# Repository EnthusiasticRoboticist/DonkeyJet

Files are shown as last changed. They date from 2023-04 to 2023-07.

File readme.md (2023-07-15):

# Workspace for DonkeyJet [Under ACTIVE CONSTRUCTION]

Introducing my ongoing robotics project, currently named **DonkeyJet**, inspired by the [Donkey Car project](https://www.donkeycar.com/). This mobile robot is built on an RC car frame and powered by Jetson Nano, providing a hands-on platform for practicing robotics knowledge. The goal is to continually enhance its capabilities while exploring various aspects of robotics technology. While I am not certain about the name DonkeyJet, I invite you to follow me on this exciting journey of discovery as I document my progress and share insights with fellow enthusiasts in my weblog [here](https://www.enthusiasticroboticist.com/).

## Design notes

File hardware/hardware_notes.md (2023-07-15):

# Mechanical Info

### Car

https://www.nitrorcx.com/51c858-16-deaertsct-aagreen-24g.html

## Gear Tooth Sensor IC

- [Sensor WebPage and CAD files](https://www.allegromicro.com/en/products/sense/magnetic-speed/general-purpose-speed-sensor-ics/ats668lsm)
- [Datasheet](https://www.allegromicro.com/~/media/Files/Datasheets/ATS668-Datasheet.ashx)
- [Purchase Link](https://www.digikey.com/short/pbw4z55j)

### Number of teeth of gears

- Motor Gear: 16
- Main shaft Gear: 50
- Differential Gear Box:
  - Drive Pinion Gear: 20 or 11 (not important actually)
  - Ring Gear: 39 (important)

- Wheel Diameter: 72.91 mm

## Clipboard

PC7 (ICP3/CLK0/OC4A)
X: 8.92
Y: -10.67

# Screws:
- M2x6    (8)
- M3x10   (3)

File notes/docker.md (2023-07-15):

# Docker Images

We are using docker for this project. [Read more here](https://www.enthusiasticroboticist.com/blog/ros-2-on-jetson-nano-using-docker/).

- [setup remote docker build](https://youtu.be/YX2BSioWyhI)
- add Jetson IP to `/etc/hosts` as `jetson`
- some docker docs
  - https://docs.docker.com/build/building/multi-platform/
- https://www.docker.com/blog/multi-arch-build-and-images-the-simple-way/

Setup for building docker image for multiple platforms which images are built natively on the corresponding hardware without emulation.

```bash
/usr/bin/dockerd -H fd:// --containerd=/run/containerd/containerd.sock
export REGISTRY="<the docker registry to be used, or dockerhub user>"

docker context create jetson --docker "host=tcp://jetson:2375"
docker context create localamd64 --docker "host=unix:///var/run/docker.sock"

# just one time
# docker buildx create --use  --driver-opt network=host --config=buildkitd.toml --name MultiPlatform
docker buildx create --use --driver-opt network=host --config=buildkitd-arm64.toml --name mybuilder jetson
docker buildx create --append --driver-opt network=host --config=buildkitd-amd64.toml --name mybuilder localamd64
```

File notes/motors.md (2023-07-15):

# motors

[Read more here](https://www.enthusiasticroboticist.com/blog/actuation-and-pca9685-with-ros-2-on-jetson-nano/)

```bash
docker run \
  --name realsense \
  --rm \
  -it \
  --privileged \
  --network host \
  -e DISPLAY \
  --runtime nvidia \
  --gpus all \
  ${REGISTRY}/ros2_realsense:latest \
  bash

  -v /dev/input:/dev/input \
  -v /dev/v4l:/dev/v4l \
  -v /dev:/dev \
  -v /proc:/proc \
  -v /sys:/sys \
# issue about Jetson.GPIO inside docker: 
# https://forums.developer.nvidia.com/t/jetson-gpio-not-working-on-python-inside-the-container/180435
python -m pip install adafruit-circuitpython-servokit Jetson.GPIO
i2cdetect -y -r 1
```

- [More about I2C in Linux](https://www.youtube.com/watch?v=-1PHQYRbAm8&ab_channel=Johannes4GNU_Linux)
- [PCA9685 datasheet](https://cdn-shop.adafruit.com/datasheets/PCA9685.pdf)
- [PCA9685 Adafruit info](https://cdn-learn.adafruit.com/downloads/pdf/16-channel-pwm-servo-driver.pdf)
- The I2C address is `0x40`.
- [About Actutation](http://docs.donkeycar.com/parts/actuators/)
- [I2C in Linux](http://embeddedcraft.org/eclinux/linuxi2c.html)

## PWM Signals
- PWM Period: 20 ms, PWM Frequency: 50Hz
- 1ms - 2ms high or Duty cycle: 1% - 10% with 50Hz freq
- Servo from left to right
- Throttle form full backward to full forward.

```
freq = 60
prescaler = 0x66 = 25M / (4096 * frequency)
i2cset -y 1 0x40 0x00 0x90
i2cset -y 1 0x40 0xFE 0x66
i2cset -y 1 0x40 0x00 0xA0

# steering
i2cset -y 1 0x40 0x0A 0x00 && \
  i2cset -y 1 0x40 0x0B 0x00 && \
  i2cset -y 1 0x40 0x0C 0xFA && \
  i2cset -y 1 0x40 0x0D 0x00

i2cset -y 1 0x40 0x0A 0x00 0x00 0x4F 0x01 i

# throttle (85 instead of 6f is good value for test)
i2cset -y 1 0x40 0x06 0x00 && \
i2cset -y 1 0x40 0x07 0x00 && \
i2cset -y 1 0x40 0x08 0x85 && \
i2cset -y 1 0x40 0x09 0x01

i2cset -y 1 0x40 0x06 0x00 0x00 0x4F 0x01 i

```

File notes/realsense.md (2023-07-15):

# Docker image with CUDA, ROS2, Realsense
- https://dev.intelrealsense.com/docs/nvidia-jetson-tx2-installation

```bash
docker buildx build \
  --platform linux/amd64,linux/arm64 \
  -f realsense.Dockerfile \
  --build-arg BASE_IMAGE=${REGISTRY}/ros2_base2:latest \
  -t ${REGISTRY}/ros2_realsense:latest \
  --push .

# on jetson run only once
sudo curl https://raw.githubusercontent.com/IntelRealSense/librealsense/master/config/99-realsense-libusb.rules -o /etc/udev/rules.d/99-realsense-libusb.rules \
  && sudo udevadm control --reload-rules \
  && sudo udevadm trigger

docker run \
  --name ros2_realsense \
  --rm \
  -it \
  --runtime nvidia \
  --network host \
  --gpus all \
  --privileged \
  -v /dev/bus/usb/:/dev/bus/usb/ \
  -e DISPLAY \
  ${REGISTRY}/ros2_realsense:latest \
  bash

# to test run the following in the docker container
rs-depth

ros2 launch realsense2_camera rs_launch.py initial_reset:=true
```

# Prepare IMU data from D435i for ROS 2

```bash
MOUNT_WS
cd ws/donkeyJet

rs-enumerate-devices  # check the device
# once
sudo udevadm control --reload-rules
udevadm trigger

docker pull ${REGISTRY}/ros2_realsense:latest

#run this to load software to T265
docker run \
  --name ros2_base \
  --rm \
  --privileged \
  -v /dev/bus/usb/:/dev/bus/usb/ \
  ${REGISTRY}/ros2_realsense_latest:latest \
  rs-pose

# for development on host:
docker run \
  --name ros2_base \
  --rm \
  -it \
  --runtime nvidia \
  --network host \
  --gpus all \
  --privileged \
  -e DISPLAY \
  -v /dev/bus/usb/:/dev/bus/usb/ \
  -v `pwd`/ros2_ws/src:/root/ros2_ws/src \
  -v `pwd`/ros2_ws_tutorial/src:/root/ros2_ws_tutorial/src \
  ${REGISTRY}/ros2_realsense:latest \
  bash 

# ${REGISTRY}/ros2_realsense:latest \

colcon build --symlink-install

# for test on jetson:
export JETSON_IP=
export HOST=""
export HOST="-H $JETSON_IP"
function RUN(){
  docker $HOST run --name ros2_ws --rm -it \
    --runtime nvidia --network host \
    --gpus all -e DISPLAY \
    --privileged -v /proc:/proc -v /dev:/dev -v /sys:/sys \
    ${REGISTRY}/ros2_ws:latest bash -ic "$@"
}

function BUILD_AND_RUN(){
  docker $HOST pull ${REGISTRY}/ros2_realsense:latest && \
  docker $HOST buildx build -f ros2_ws.Dockerfile  --build-arg BASE_IMAGE=${REGISTRY}/ros2_realsense:latest   -t ${REGISTRY}/ros2_ws:latest . && \
  RUN "$@"
}

ros2 run bot_hardware realsense
BUILD_AND_RUN "ros2 run bot_hardware realsense --ros-args --log-level debug" # --ros-args --log-level debug

ros2 run tf2_tools view_frames.py
ros2 launch realsense2_camera rs_launch.py
ros2 run tf2_ros tf2_echo camera_pose_frame odom_frame

reset; colcon build && \
  ./build/bot_hardware/bot_hardware_test --gtest_filter="realsense_lib.*"
```

# build realsense image
```bash
docker buildx build \
  --platform linux/amd64,linux/arm64 \
  -f realsense.Dockerfile \
  --build-arg BASE_IMAGE=${REGISTRY}/ros2_base:latest \
  -t ${REGISTRY}/ros2_realsense:latest \
  --push .
```

## Expected IMU type

- More information about message type can be found [here](https:docs.ros2.org/foxy/api/nav_msgs/msg/Odometry.html).
- Example of including librealsense SKD into a [ros2 CMakeLists.txt file](https:github.com/IntelRealSense/realsense-ros/blob/ros2-development/realsense2_camera/CMakeLists.txt)
- Realsense How-to [wiki page](https:github.com/IntelRealSense/librealsense/wiki/API-How-To).
- Realsense cpp [IMU example](https:github.com/GruffyPuffy/imutest/blob/master/imutest.cpp).

# Notes

- You need to plug the USB first, then run the container. When you re-plug the USB, you need to kill the docker container and re-run it. Otherwise, realsense device would not be visible within the container.
- Sometimes the IMU streams are not coming. I don't know why. Re-plugging could help.
- reading imu info
- T265 doesn't have memory for firmware and usb volume bind and container issues

```cpp
rs2::pipeline pipe;
rs2::config cfg;
cfg.enable_stream(RS2_STREAM_ACCEL);
cfg.enable_stream(RS2_STREAM_GYRO);
cfg.enable_stream(RS2_STREAM_DEPTH);
pipe.start(cfg);

while (true)
{
  rs2::frameset frameset = pipe.wait_for_frames(1000);

  if (rs2::motion_frame accel_frame = frameset.first_or_default(RS2_STREAM_ACCEL))
  {
    rs2_vector accel_sample = accel_frame.get_motion_data();
    std::cout << "Accel:" << accel_sample.x << ", " << accel_sample.y << ", " << accel_sample.z << std::endl;
  }

  if (rs2::motion_frame gyro_frame = frameset.first_or_default(RS2_STREAM_GYRO))
  {
    rs2_vector gyro_sample = gyro_frame.get_motion_data();
    std::cout << "Gyro:" << gyro_sample.x << ", " << gyro_sample.y << ", " << gyro_sample.z << std::endl;
  }
}

auto callback = [&](const rs2::frame &frame)
{
  if (frame.is<rs2::frameset>())
  {
    std::cout << "Depth data" << std::endl;
  } else if (frame.is<rs2::motion_frame>())
  {
    auto motion = frame.as<rs2::motion_frame>();
    const auto &stream_type = motion.get_profile().stream_type();
    std::cout << "gyro: " << (stream_type == RS2_STREAM_GYRO)
              << ", accel: " << (stream_type == RS2_STREAM_ACCEL) << std::endl;
  } else if(frame.is<rs2::pose_frame>())
  {
    std::cout << "pose frame" << std::endl;
  }
};
```

```cpp
#include <librealsense2/rs.hpp>
#include <iostream>

int main()
{
  rs2::pipeline pipe;
  rs2::config cfg;
  cfg.enable_stream(RS2_STREAM_ACCEL);
  cfg.enable_stream(RS2_STREAM_GYRO);
  pipe.start(cfg);

  while (true) // Application still alive?
  {
    rs2::frameset frameset = pipe.wait_for_frames(1000);

    if (rs2::motion_frame accel_frame = frameset.first_or_default(RS2_STREAM_ACCEL))
    {
      rs2_vector accel_sample = accel_frame.get_motion_data();
      std::cout << "Accel:" << accel_sample.x << ", " << accel_sample.y << ", " << accel_sample.z << std::endl;
    }

    if (rs2::motion_frame gyro_frame = frameset.first_or_default(RS2_STREAM_GYRO))
    {
      rs2_vector gyro_sample = gyro_frame.get_motion_data();
      std::cout << "Gyro:" << gyro_sample.x << ", " << gyro_sample.y << ", " << gyro_sample.z << std::endl;
    }
  }
  return 0;
}
```

```cpp
#include <librealsense2/rs.hpp>
#include <iostream>

int main(){
  auto callback = [&](const rs2::frame &frame)
  {
    if (frame.is<rs2::frameset>())
    {
      std::cout << "Depth data" << std::endl;
    } else if (frame.is<rs2::motion_frame>())
    {
      auto motion = frame.as<rs2::motion_frame>();
      const auto &stream_type = motion.get_profile().stream_type();
      std::cout << "gyro: " << (stream_type == RS2_STREAM_GYRO)
                << ", accel: " << (stream_type == RS2_STREAM_ACCEL) << std::endl;
    } else if(frame.is<rs2::pose_frame>())
    {
      std::cout << "pose frame" << std::endl;
    }
  };

  rs2::pipeline pipe;
  rs2::config cfg;
  cfg.enable_stream(RS2_STREAM_ACCEL);
  cfg.enable_stream(RS2_STREAM_GYRO);
  cfg.enable_stream(RS2_STREAM_DEPTH); 

  std::this_thread::sleep_for(std::chrono::milliseconds(500));
  pipe.start(cfg, callback);
  while (true){}
  return 0;
}
```

```cpp
{
  auto callback = [&](const rs2::frame &frame)
  {
    // callback code as before
  };
  rs2::context ctx;
  rs2::pipeline pipe_t265;
  rs2::config rs_cfg_t265;
  rs2::pipeline pipe_d435;
  rs2::config rs_cfg_d435;

  for (auto dev : ctx.query_devices())
  {
    std::cout << dev.get_info(RS2_CAMERA_INFO_NAME) << std::endl;
    if (strcmp(dev.get_info(RS2_CAMERA_INFO_NAME), "Intel RealSense D435") == 0)
    {
      rs_cfg_d435.enable_stream(RS2_STREAM_DEPTH); // , 256, 144, RS2_FORMAT_Z16, 90
    }
    else if (strcmp(dev.get_info(RS2_CAMERA_INFO_NAME), "Intel RealSense T265") == 0)
    {
      rs_cfg_t265.enable_stream(RS2_STREAM_ACCEL);
      rs_cfg_t265.enable_stream(RS2_STREAM_GYRO);
      rs_cfg_t265.enable_stream(RS2_STREAM_POSE);
    }
  }

  pipe_d435.start(rs_cfg_d435, callback);
  pipe_t265.start(rs_cfg_t265, callback);

  while (true)
  {
  }
}
```

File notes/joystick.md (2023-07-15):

# Joystick (Controller)

[Read more](https://www.enthusiasticroboticist.com/blog/using-bluetooth-controller-with-ros-2-on-jetson-nano/)
[About Joystick in Linux](https://opencoursehub.cs.sfu.ca/bfraser/grav-cms/cmpt433/links/files/2022-student-howtos/LinuxJoystick.hLibrary.pdf).

### Test the joystick

With GUI
```bash
sudo apt install -y jstest-gtk
jstest-gtk
```

Without GUI
```bash
jstest /dev/input/js0
```

With ros
```
docker -H 192.168.68.68 pull ${REGISTRY}/ros2_base2:latest
docker -H 192.168.68.68 run \
  --rm -it  --runtime nvidia --network host \
  --gpus all --privileged \
  -v /dev:/dev -v /proc:/proc -v /sys:/sys \
  ${REGISTRY}/ros2_base2:latest \
  bash
```

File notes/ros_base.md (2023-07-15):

# ROS 2

## Humble

```bash
docker buildx build \
  --platform linux/amd64,linux/arm64 \
  -f ros2_humble.Dockerfile \
  -t ${REGISTRY}/ros2_humble:latest \
  --push .

docker pull ${REGISTRY}/ros2_humble:latest

docker run \
  --name humble \
  --rm \
  -it \
  --runtime nvidia \
  --network host \
  --gpus all \
  -e DISPLAY \
  ${REGISTRY}/ros2_humble:latest \
  bash

colcon build --merge-install --cmake-args -DCMAKE_BUILD_TYPE=Release --packages-up-to-regex python_orocos_kdl_vendor
colcon build --merge-install --cmake-args -DCMAKE_BUILD_TYPE=Release --packages-up-to-regex qt_gui_cpp python_orocos_kdl_vendor
colcon build --merge-install --cmake-args -DCMAKE_BUILD_TYPE=Release --packages-select qt_gui_cpp python_orocos_kdl_vendor

update-alternatives --remove python /usr/bin/python3.9
update-alternatives --remove python3 /usr/bin/python3.9

# RUN python -m pip install -U \
#     PyQt5 \
#   && apt install --no-install-recommends -y \
#     sip-dev pyqt5-dev \
#     python3-apt \
#   && python3.6 /usr/bin/add-apt-repository -y ppa:beineri/opt-qt-5.15.2-bionic \
#   && apt update \
#   && apt install 
```

## Foxy

### Docker image with CUDA and ROS2

```bash
docker buildx build \
  --platform linux/amd64,linux/arm64 \
  -f ros2_base.Dockerfile \
  -t ${REGISTRY}/ros2_base2:latest \
  --push .

docker buildx build \
  --platform linux/amd64,linux/arm64 \
  -f ros2_base.Dockerfile \
  -t ${REGISTRY}/ros2_base2:latest \
  --output=tar .

# test the images
docker pull ${REGISTRY}/ros2_base2:latest
docker run \
  --name ros2_base \
  --rm \
  -it \
  --runtime nvidia \
  --network host \
  --gpus all \
  -e DISPLAY \
  ${REGISTRY}/ros2_base2:latest \
  bash

# test images
ros2 run demo_nodes_cpp talker
ros2 run demo_nodes_cpp listener
```

## ROS2 Workspace Docker Container

```bash
# build my image
docker buildx build \
  --platform linux/amd64,linux/arm64 \
  -f ros2_ws.Dockerfile \
  --build-arg BASE_IMAGE=${REGISTRY}/ros2_base2:latest \
  -t ${REGISTRY}/ros2_ws:latest \
  --push .

docker buildx build \
  --platform linux/amd64,linux/arm64 \
  -f ros2_ws.Dockerfile \
  --build-arg BASE_IMAGE=${REGISTRY}/ros2_base2:latest \
  -t ${REGISTRY}/ros2_ws:latest \
  . --output registry.insecure=true,push=true,type=image
```

## Docker For Development
```bash
export JETSON_IP=

function BUILD_AND_RUN(){
  docker -H $JETSON_IP pull ${REGISTRY}/ros2_base2:latest
  docker -H $JETSON_IP buildx build -f ros2_ws.Dockerfile  --build-arg BASE_IMAGE=${REGISTRY}/ros2_base2:latest   -t ${REGISTRY}/ros2_ws:latest .
  docker -H $JETSON_IP run --name ros2_ws --rm -it --runtime nvidia --network host --gpus all --privileged -e DISPLAY -v /dev:/dev -v /proc:/proc -v /sys:/sys ${REGISTRY}/ros2_ws:latest bash -ic "$@"
}
export EXEC_RUN="docker -H $JETSON_IP exec -it ros2_ws /bin/bash -ic"

# Run nodes separately
BUILD_AND_RUN "ros2 run bot_hardware joy"
$EXEC_RUN "ros2 run bot_hardware pca9685"

# run the launch file
BUILD_AND_RUN "ros2 launch bot_hardware manual_control_launch.py"

# local dev env
docker run \
  --name ros2_base \
  --rm \
  -it \
  --runtime nvidia \
  --network host \
  --gpus all \
  --privileged \
  -e DISPLAY \
  -v `pwd`/ros2_ws/src:/root/ros2_ws/src \
  -v `pwd`/ros2_ws_tutorial/src:/root/ros2_ws_tutorial/src \
  ${REGISTRY}/ros2_base2:latest \
  bash 
```

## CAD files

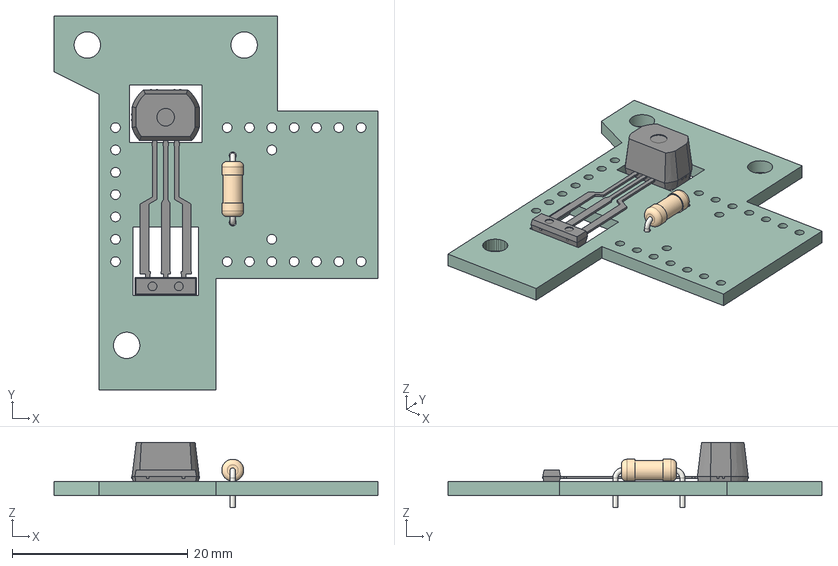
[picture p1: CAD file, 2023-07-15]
hardware/encoder/encoder.step
36.8 x 42.5 x 7.41 mm
encoder PCB

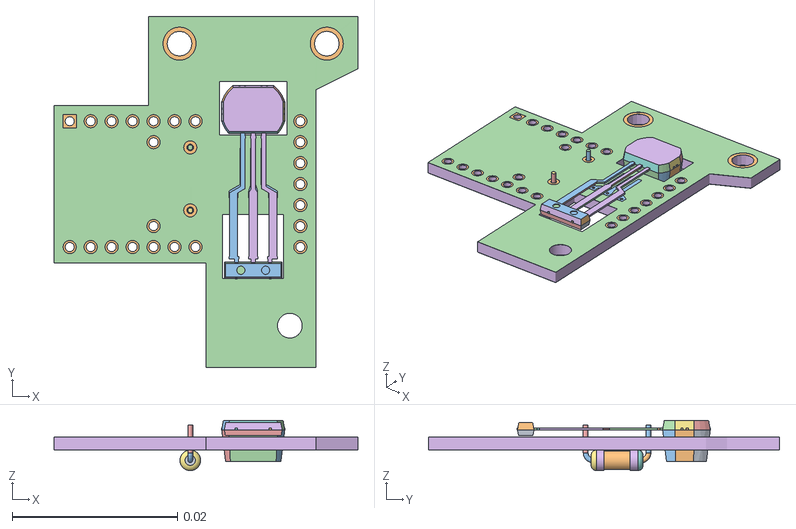
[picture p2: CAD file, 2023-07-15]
hardware/encoder/pcb.obj
0.0368 x 0.0425 x 0.00609
SHAPE_1_IndexedFaceSet
SHAPE_2_IndexedFaceSet
SHAPE_3_IndexedFaceSet
SHAPE_4_IndexedFaceSet
SHAPE_5_IndexedFaceSet
SHAPE_6_IndexedFaceSet
SHAPE_7_IndexedFaceSet
SHAPE_8_IndexedFaceSet
SHAPE_9_IndexedFaceSet
SHAPE_10_IndexedFaceSet
SHAPE_11_IndexedFaceSet
SHAPE_12_IndexedFaceSet
SHAPE_13_IndexedFaceSet
SHAPE_14_IndexedFaceSet
SHAPE_15_IndexedFaceSet
SHAPE_16_IndexedFaceSet
SHAPE_17_IndexedFaceSet
SHAPE_18_IndexedFaceSet
SHAPE_19_IndexedFaceSet
SHAPE_20_IndexedFaceSet
SHAPE_21_IndexedFaceSet
SHAPE_22_IndexedFaceSet
SHAPE_23_IndexedFaceSet
SHAPE_24_IndexedFaceSet
SHAPE_25_IndexedFaceSet
SHAPE_26_IndexedFaceSet
SHAPE_27_IndexedFaceSet
SHAPE_28_IndexedFaceSet
SHAPE_29_IndexedFaceSet
SHAPE_30_IndexedFaceSet
SHAPE_31_IndexedFaceSet
SHAPE_32_IndexedFaceSet
SHAPE_33_IndexedFaceSet
SHAPE_34_IndexedFaceSet
SHAPE_35_IndexedFaceSet
SHAPE_36_IndexedFaceSet
SHAPE_37_IndexedFaceSet
SHAPE_38_IndexedFaceSet
SHAPE_39_IndexedFaceSet
SHAPE_40_IndexedFaceSet
SHAPE_41_IndexedFaceSet
SHAPE_42_IndexedFaceSet
SHAPE_43_IndexedFaceSet
SHAPE_44_IndexedFaceSet
SHAPE_45_IndexedFaceSet
SHAPE_46_IndexedFaceSet
SHAPE_47_IndexedFaceSet
SHAPE_48_IndexedFaceSet
SHAPE_49_IndexedFaceSet
SHAPE_50_IndexedFaceSet
SHAPE_51_IndexedFaceSet
SHAPE_52_IndexedFaceSet
SHAPE_53_IndexedFaceSet
SHAPE_54_IndexedFaceSet
SHAPE_55_IndexedFaceSet
SHAPE_56_IndexedFaceSet
SHAPE_57_IndexedFaceSet
SHAPE_58_IndexedFaceSet
SHAPE_59_IndexedFaceSet
SHAPE_60_IndexedFaceSet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

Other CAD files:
hardware/encoder/pcb.blend

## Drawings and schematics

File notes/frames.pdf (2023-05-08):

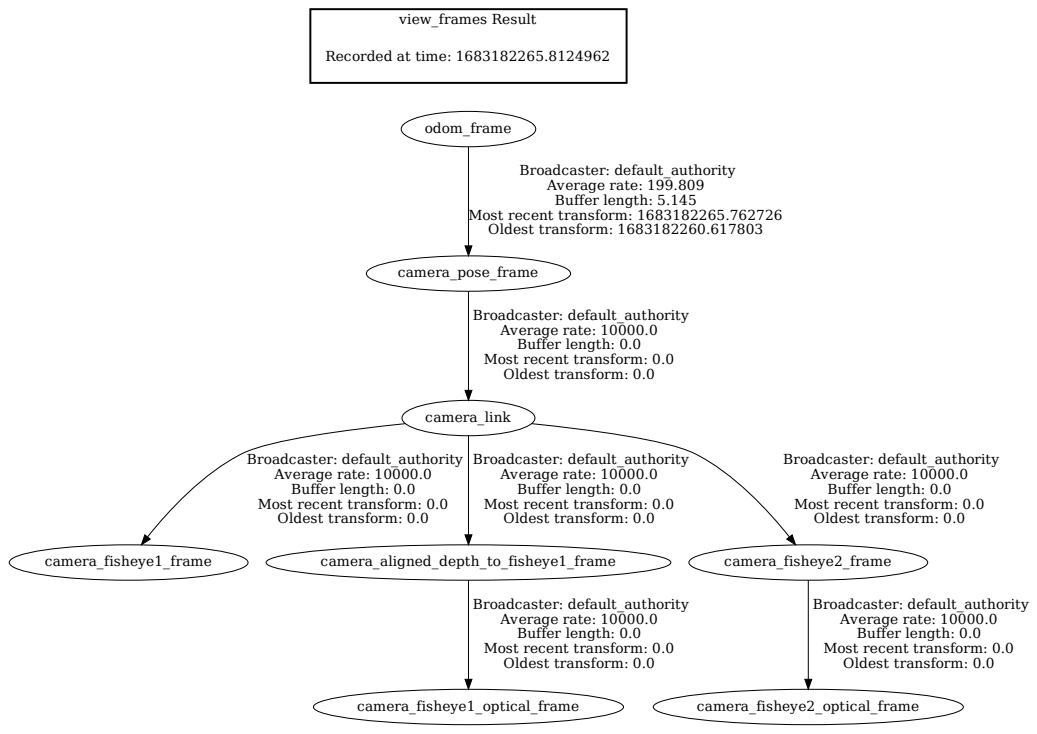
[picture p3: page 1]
view_frames Result; odom_frame; camera_pose_frame; Broadcaster: default_authority Average rate: 199.809 Buffer length: 5.145; camera_link; camera_fisheye1_frame; camera_aligned_depth_to_fisheye1_frame; camera_fisheye2_frame; camera_fisheye1_optical_frame; camera_fisheye2_optical_frame

Recorded at time: 1683182265.8124962

Most recent transform: 1683182265.762726
Oldest transform: 1683182260.617803

Broadcaster: default_authority
Average rate: 10000.0
Buffer length: 0.0
Most recent transform: 0.0
Oldest transform: 0.0

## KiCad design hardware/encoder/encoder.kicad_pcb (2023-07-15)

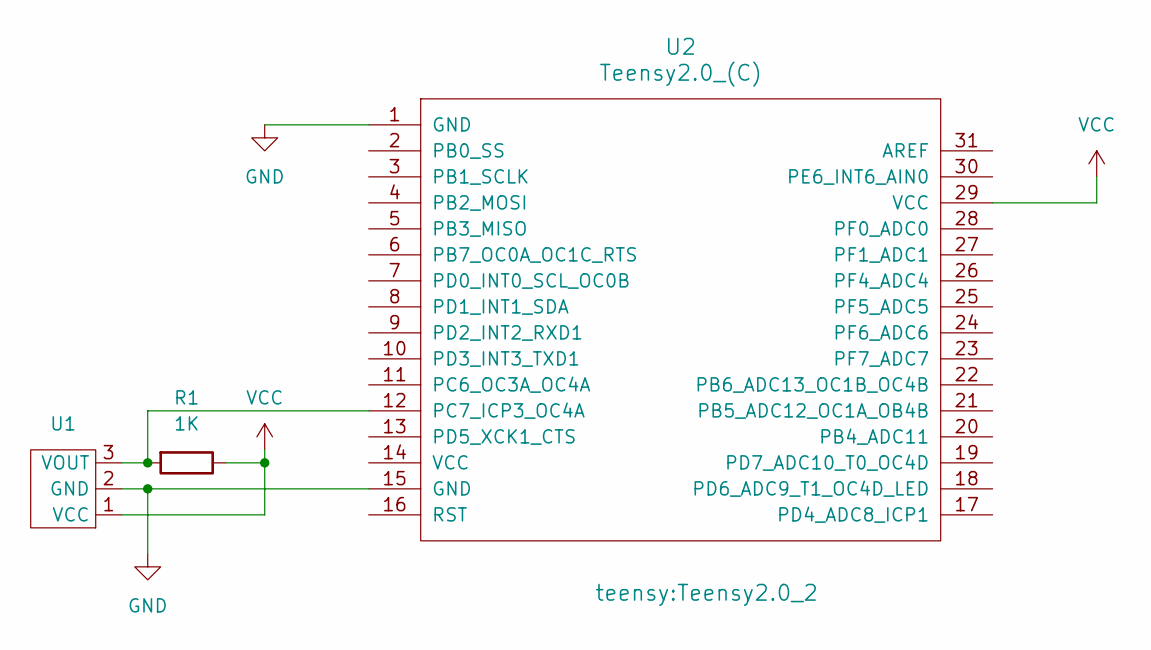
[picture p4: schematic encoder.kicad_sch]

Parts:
R1: 1K; R_Axial_DIN0207_L6.3mm_D2.5mm_P7.62mm_Horizontal
U1: ATS668LSM_1
U2: Teensy2.0_(C); Teensy2.0_2

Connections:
GND: U1.2 (GND), U2.1 (GND), U2.15 (GND)
unnamed: R1.2, U1.3 (VOUT), U2.12 (PC7_ICP3_OC4A)
VCC: R1.1, U1.1 (VCC), U2.29 (VCC)

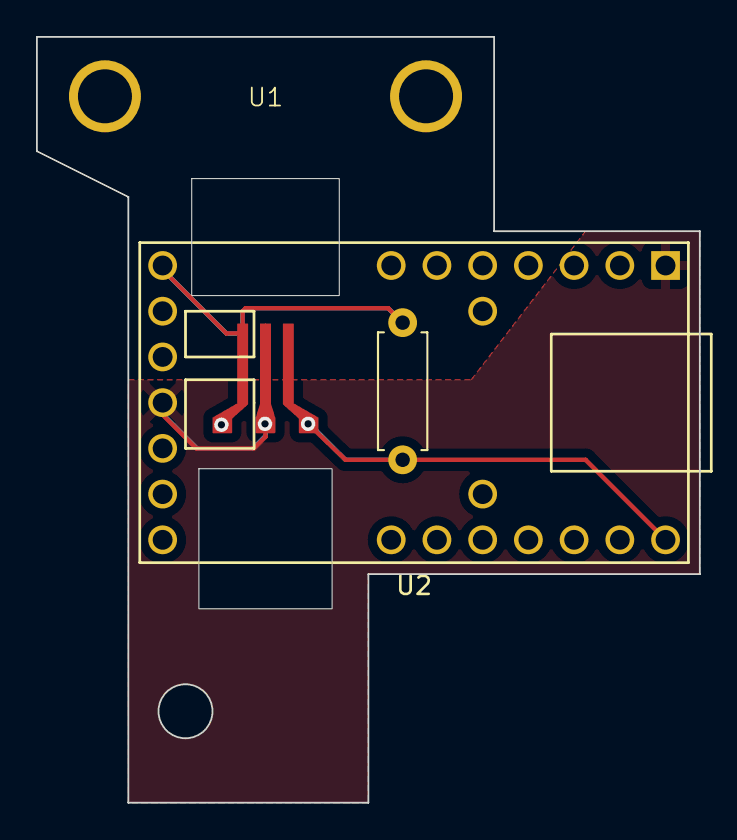
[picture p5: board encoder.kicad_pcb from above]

Board: 2 copper layers, 36.8 x 42.5 mm, 3 parts (0 on the bottom side), 3 nets.

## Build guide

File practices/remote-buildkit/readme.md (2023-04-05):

NOT WORKING. GIVING UP

```bash
docker buildx use default

docker run --rm \
  --name=remote-buildkitd \
  --privileged \
  --gpus all \
  --runtime nvidia \
  --network host \
  -v /usr/bin/nvidia-container-runtime:/usr/bin/nvidia-container-runtime \
  -v /usr/bin/nvidia-container-runtime-hook:/usr/bin/nvidia-container-runtime-hook \
  -v /usr/share/lintian/overrides/nvidia-container-toolkit:/usr/share/lintian/overrides/nvidia-container-toolkit \
  -v /etc/nvidia-container-runtime:/etc/nvidia-container-runtime \
  -v /usr/lib/x86_64-linux-gnu:/usr/lib/x86_64-linux-gnu \
  -v /usr/local/cuda-11.5:/usr/local/cuda-11.5 \
  -v /run/containerd/containerd.sock:/run/containerd/containerd.sock \
  -v /var/run/docker.sock:/var/run/docker.sock \
  moby/buildkit:latest \
  --addr tcp://0.0.0.0:1234 \
  --oci-worker-binary=/usr/bin/nvidia-container-runtime \
  --allow-insecure-entitlement security.insecure

docker exec -it remote-buildkitd sh
ln -s /usr/bin/buildkit-runc /usr/bin/runc
ln -s /usr/local/cuda-11.5 /usr/local/cuda

# on a new terminal (probably only once)
docker buildx create \
  --use \
  --name remote-container \
  --driver remote \
  tcp://localhost:1234

# on a new terminal
docker buildx build -f Dockerfile . --no-cache --progress plain
```

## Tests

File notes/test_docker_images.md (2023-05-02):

# Fixing Realsense issues

docker image

```bash
# On Jetson
MOUNT_WS

# initial_reset:=true
ros2 launch realsense2_camera rs_launch.py depth_module.profile:=640x480x6 rgb_camera.profile:=640x480x6 initial_reset:=true

# log_level:=DEBUG 
# enable_color:=false
```

# CUDA test

```bash
# on host
docker buildx build \
  --platform linux/amd64,linux/arm64 \
  -f cudatest.Dockerfile \
  -t ${REGISTRY}/cudatest:latest \
  --build-arg BASE_IMAGE=${REGISTRY}/ros2_base2:latest \
  --push .

docker pull ${REGISTRY}/cudatest:latest
docker run --pull=always --rm -it --runtime nvidia ${REGISTRY}/cudatest:latest 
```

# Experiment with remote buildkit

```bash
docker run --rm \
  --name=remote-buildkitd \
  --privileged \
  --gpus all \
  -p 1234:1234 \
  -v /usr/bin/nvidia-container-runtime:/usr/bin/nvidia-container-runtime \
  -v /etc/nvidia-container-runtime:/etc/nvidia-container-runtime \
  -v /usr/local:/usr/local \
  moby/buildkit:latest \
  --addr tcp://0.0.0.0:1234 \
  --oci-worker-binary=/usr/bin/nvidia-container-runtime

docker buildx create \
  --use \
  --name remote-container \
  --driver remote \
  tcp://${JETSON_IP}:1234

docker exec -it remote-buildkitd sh
ln -s /usr/bin/buildkit-runc /usr/bin/runc

docker buildx build \
  --platform linux/arm64 \
  -f cudatest.Dockerfile \
  -t ${REGISTRY}/cudatest:latest \
  --push .
```

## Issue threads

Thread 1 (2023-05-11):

Any chance to make compatible with i2cpwm_board

Heavy02011, 2023-05-11:
Great project!
I would like to use it within a my ROS2 container running on a Jetson Nano and got it running receiving & performing steering commands but not throttle as I am not quite sure how to map js axis correctly. In my case (ps3) steering is on axis 0 and throttle on axis 3 but changing that in the code does not work for throttle. using the topics from i2cpwm_board would help to debug and find the error, but here we only have topic „joy“. any hints? thx

EnthusiasticRoboticist, 2023-05-11:
Hi @Heavy02011, Thanks :)
1. I will check `i2cpwm_board`. I usually use the `jstest` to determine which axis number corresponds to what. You may have tried that.
2. Yes. That makes sense. :) Would you happen to know the convention for message type for the steer and throttle?

Heavy02011, 2023-05-11:
I checked https://github.com/mentor-dyun/ros-i2cpwmboard.git  under ROS melodic and found the following topics are implemented: /servos_absolute /servos_drive /servos_proportional working with these [messages](https://github.com/mentor-dyun/ros-i2cpwmboard/tree/master/msg)

Heavy02011, 2023-05-12:
tried [this](https://github.com/Heavy02011/DonkeyJet/blob/001-i2cpwm_board/ros2_ws/src/bot_hardware/src/pca9685_board.cpp), but did not get the i2cpwm_board_msgs included correctly

EnthusiasticRoboticist, 2023-05-14:
I added a new `Control` message as the input of the PCA node, in this commit: https://github.com/EnthusiasticRoboticist/DonkeyJet/commit/f36b06b224fc0ef86142ac7bf0216be50e21fb99

Heavy02011, 2023-05-16:
Does this allow to set the PWM limits (min, zero, max) individually? I observed that my PWM „zero“ is a bit off, which is difficult to compensate for when you want to drive backwards.

EnthusiasticRoboticist, 2023-05-16:
The class `Float2ServoMap` [here](https://github.com/EnthusiasticRoboticist/DonkeyJet/blob/f36b06b224fc0ef86142ac7bf0216be50e21fb99/ros2_ws/src/bot_hardware/src/pca9685.cpp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) is responsible to map from the floating number in [-1,+1] to integer value for the PWM signal given the minimum and maximum required high times of the signal in milliseconds. I guess with playing the arguments [here](https://github.com/EnthusiasticRoboticist/DonkeyJet/blob/f36b06b224fc0ef86142ac7bf0216be50e21fb99/ros2_ws/src/bot_hardware/src/pca9685.cpp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) you should be able to tune it.

Are you saying when you set the throttle to 0 (floating value), the car moves?

EnthusiasticRoboticist, 2023-05-19:
Happy it works.

Yes, I remembered, I have introduced an offset [here](https://github.com/EnthusiasticRoboticist/DonkeyJet/blob/main/ros2_ws/src/bot_hardware/src/pca9685.cpp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) for steering which is hardcoded right now. You can add similar to the throttle if you need to.
My car wasn't going entirely straight at zero steering value. Actually, there is backlash in my car steering mechanism which I am ignoring right now.

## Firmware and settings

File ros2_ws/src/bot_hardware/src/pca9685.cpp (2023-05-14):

#include <memory>
#include <unistd.h>
#include <fcntl.h>
#include <linux/i2c-dev.h>
#include <sys/ioctl.h>
#include "rclcpp/rclcpp.hpp"
#include "bot_hardware/msg/control.hpp"

using std::placeholders::_1;

#define I2C_ADDRESS 0x40
#define PCA9685_MODE1 0x00
#define PCA9685_MODE2 0x01
#define PCA9685_LED0_ON_L 0x06
#define PCA9685_PRESCALE 0xFE

#define THROTTLE_PWM_CHANNEL 0
#define STEERING_PWM_CHANNEL 1


/**
 * @brief This class can be used to map a float 
 * value between -1 and 1 to int value for the 
 * servos based on the PWM frequency.
 */
class Float2ServoMap
{
public:
  using Ptr = std::shared_ptr<Float2ServoMap>;

  /**
   * @brief builder function
   * 
   * @param[in] freq        Desired frequency of the PWM signal
   * @param[in] minMiliSec  Minimum high time of the PWM singal in milliseconds
   * @param[in] maxMiliSec  Maximum hight time of the PWM singnal in milliseconds
   * @param[in] maxPWM      The maximum value for the PWM (defining the resolution for PWM signal generator)
   * @return Float2ServoMap::Ptr 
   */
  static Float2ServoMap::Ptr create(float freq, float minMiliSec, float maxMiliSec, unsigned int maxPWM)
  {
    return std::make_shared<Float2ServoMap>(freq, minMiliSec, maxMiliSec, maxPWM);
  }

  float calPwm(float f)
  {
    return m_ * f + b_;
  }

  Float2ServoMap(float freq, float minMiliSec, float maxMiliSec, unsigned int maxPWM):
    m_(0), b_(0)
  {
    float ms_2_percent = float(freq) / 1000.0 /* ms */;
    float minPWMv = minMiliSec * ms_2_percent * maxPWM;
    float maxPWMv = maxMiliSec * ms_2_percent * maxPWM;
    float Fmin = -1.0;
    float Fmax = 1.0;
    m_ = (maxPWMv - minPWMv) / (Fmax - Fmin);
    b_ = minPWMv - m_ * Fmin;
  }
private:
  float m_, b_;
};

class PCA9685 : public rclcpp::Node
{
public:
  PCA9685() : Node("pca9685")
  {
    init_hardware();
    control_subscription_ = this->create_subscription<bot_hardware::msg::Control>(
        "/control", 10, std::bind(&PCA9685::control_callback, this, _1));
  }

  ~PCA9685()
  {
    // Close the I2C device
    set_pwm(0, 0, 0);
    set_pwm(1, 0, 0);
    close(i2c_fd_);
  }

private:
  void init_hardware()
  {
    // Set the PWM frequency
    pwm_freq_ = 60.0;
    steeringMap = Float2ServoMap::create(pwm_freq_, 1.0, 2.0, 4095u);
    throttleMap = Float2ServoMap::create(pwm_freq_, 1.0, 2.0, 4095u);

    // Get the I2C device file descriptor
    i2c_fd_ = open("/dev/i2c-1", O_RDWR);
    while (i2c_fd_ < 0)
    {
      RCUTILS_LOG_ERROR_NAMED(get_name(), "Failed to open I2C device: %d, trying again in 1 sec.", i2c_fd_);
      usleep(1000000);
      i2c_fd_ = open("/dev/i2c-1", O_RDWR);
    }

    // Set the I2C slave address
    dev_address_ = I2C_ADDRESS;
    if (ioctl(i2c_fd_, I2C_SLAVE, dev_address_) < 0)
    {
      RCUTILS_LOG_ERROR_NAMED(get_name(), "Failed to set I2C slave address");
      return;
    }
    
    set_frequency(pwm_freq_);

    // Set the default PWM values
    set_pwm(0, 0, 0);
    set_pwm(1, 0, 0);
  }

  // Set the PWM frequency (in Hz)
  void set_frequency(uint16_t frequency)
  {
    uint8_t prescale = (uint8_t)(std::round(25000000.0 / (4096.0 * frequency)) - 1);
    write_reg(PCA9685_MODE1, 0b00010000); 
    usleep(1000);
    write_reg(PCA9685_PRESCALE, prescale);
    write_reg(PCA9685_MODE1, 0b10100000);
    usleep(1000);
    // write_reg(PCA9685_MODE2, 0x00);
    // usleep(1000);
  }

  // Set the PWM duty cycle for a specific channel
  void set_pwm(uint8_t channel, uint16_t on_time, uint16_t off_time)
  {
    uint8_t reg_offset = PCA9685_LED0_ON_L + 4 * channel;
    uint8_t on_time_low = on_time & 0xFF;
    uint8_t on_time_high = (on_time >> 8) & 0x0F;
    uint8_t off_time_low = off_time & 0xFF;
    uint8_t off_time_high = (off_time >> 8) & 0x0F;

    write_reg(reg_offset, on_time_low);
    write_reg(reg_offset + 1, on_time_high);
    write_reg(reg_offset + 2, off_time_low);
    write_reg(reg_offset + 3, off_time_high);
  }

  void write_reg(uint8_t reg, uint8_t data)
  {
    uint8_t buf[2] = {reg, data};
    if (write(i2c_fd_, buf, 2) != 2)
    {
      RCUTILS_LOG_ERROR_NAMED(get_name(), "Failed to write I2C register value");
    }
  }

  uint8_t read_reg(uint8_t reg)
  {
    uint8_t buf[] = {reg};
    if (write(i2c_fd_, buf, 1) != 2)
    {
      RCUTILS_LOG_ERROR_NAMED(get_name(), "Failed to write I2C register value");
    }
    if (read(i2c_fd_, buf, 1) != 2)
    {
      RCUTILS_LOG_ERROR_NAMED(get_name(), "Failed to read I2C register value");
    }
    return buf[0];
  }

  void control_callback(const bot_hardware::msg::Control::SharedPtr control_msg)
  {
    if (control_msg->throttle != bot_hardware::msg::Control::INVALID)
    {
      setThrottle(control_msg->throttle);
    } else if (control_msg->steering != bot_hardware::msg::Control::INVALID)
    {
      setSteering(control_msg->steering);
    }
  }

  /**
   * @brief Set the Throttle object
   * 
   * @param[in] throttle between -1 and 1 respectively full backward and full forward
   */
  void setThrottle(float throttle)
  {
    throttle *= -1.0;
    if (std::abs(throttle) < 0.001 ) throttle = 0;
    uint16_t pwm = (uint16_t)(std::round(throttleMap->calPwm(throttle))) & 0x0FFF ;
    RCLCPP_DEBUG(this->get_logger(), "THROTTLE %d, RAW %f", pwm, throttle);
    set_pwm(THROTTLE_PWM_CHANNEL, 0, pwm);
  }

  /**
   * @brief Set the Steering object
   * 
   * @param steering between -1 and 1
   */
  void setSteering(float steering)
  {
    steering *= -1.0;
    if (std::abs(steering) < 0.0001 ) steering = 0;
    steering += 0.29;
    uint16_t pwm = (uint16_t)(std::round(steeringMap->calPwm(steering))) & 0x0FFF ;
    RCLCPP_DEBUG(this->get_logger(), "STEERING %d, RAW %f", pwm, steering);
    set_pwm(STEERING_PWM_CHANNEL, 0, pwm);
  }

  rclcpp::Subscription<bot_hardware::msg::Control>::SharedPtr control_subscription_;
  int i2c_fd_;
  uint8_t dev_address_;
  float pwm_freq_;
  Float2ServoMap::Ptr steeringMap;
  Float2ServoMap::Ptr throttleMap;
};

int main(int argc, char *argv[])
{
  rclcpp::init(argc, argv);
  rclcpp::spin(std::make_shared<PCA9685>());
  rclcpp::shutdown();
  return 0;
}

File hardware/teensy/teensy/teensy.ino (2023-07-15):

#define ICP_PIN 10 // Input Capture Pin
#define LED_PIN 11
#define CPU_PRESCALE(n) (CLKPR = 0x80, CLKPR = (n))
#define CPU_16MHz 0x00
#define TIMER3_CLOCK_PRESCALAR 8
#define WHEEL_GEAR_N_TEETH 39
#define WHEEL_DIAMETER 0.07291
#define SAMPLING_TIME 0.01

void printMeasuremets();

class SpeedMesaurement {
public:
  void onTimerOverflowInterrupt() {
    if (tickCounter == 0)
    {
      speed = 0;
      prevCapture = 0;
    } else {
      double tickPerSecond = tickCounter / accum_time;
      speed = tickPerSecond * SpeedMesaurement::TICK_PER_SECOND_TO_METER_PER_SECOND_FACTOR;
      tickCounter = 0;
      accum_time = 0;
    }
    printMeasuremets();
  }

  void onInputCaptureInterrupt() {
    unsigned int currentCapture = (ICR3L) | (ICR3H << 8);
    tickCounter += 1;
    accum_time += (currentCapture - prevCapture) * SpeedMesaurement::TICK_TO_SECOND_FACTOR;;
    prevCapture = currentCapture;
  }
  void begin() {
    pinMode(ICP_PIN, INPUT);  // INPUT_PULLUP , INPUT
    pinMode(LED_PIN, OUTPUT);
    cli();          // disable global interrupts
    TCCR3A = 0x00;
    // (TCNT3L) |(TCNT3H << 8) timer values
    // OCR3xH && OCR3xL output compare registers, x = A, B, C
    unsigned int outputCompare = F_CPU / TIMER3_CLOCK_PRESCALAR * SAMPLING_TIME;
    // outputCompare = 20000
    OCR3AH = (outputCompare >> 8);
    OCR3AL = (outputCompare | 0xFF);
    // ICR3H && ICR3L Input capture values
    // TIMSK3 interrupt mask
    TIFR3 = (1 << ICF3) | (1 << OCF3A) | (1 << TOV3); /* clear input capture flag */
    TIMSK3 = (1 << ICIE3) | (1 << OCIE3A); // TOIE3: overflow Int, ICIE3 Input Capture Interrupt, OCIE3A: OC A interrupt
    TCCR3B = (1 << ICES3) | (1 << CS31) | (1 << WGM32);  // | (1 << CS30) (1 << ICNC3) noise canceller & rising edge & clock on (8 prescalar)
    sei(); // enable global interrupts
  }
public:
  static double TICK_TO_SECOND_FACTOR;
  static double TICK_PER_SECOND_TO_METER_PER_SECOND_FACTOR;
  unsigned int prevCapture;
  bool isPrevCaptureValid;
  unsigned int tickCounter = 0;
  double accum_time = 0;
  double speed = 0;
};

double SpeedMesaurement::TICK_TO_SECOND_FACTOR = 1.0 / (F_CPU / TIMER3_CLOCK_PRESCALAR);
double SpeedMesaurement::TICK_PER_SECOND_TO_METER_PER_SECOND_FACTOR = (M_PI / WHEEL_GEAR_N_TEETH) * (WHEEL_DIAMETER/2);

SpeedMesaurement speedMeas;

void setup() {
  CPU_PRESCALE(CPU_16MHz);
  speedMeas.begin();
}

void printMeasuremets()
{
  Serial.println(speedMeas.speed);
  if (speedMeas.speed == 0) {
    digitalWrite(LED_PIN, false);
  }
}

void loop() {
}

ISR(TIMER3_CAPT_vect) {
  // Timer 3 input capture interrupt
  speedMeas.onInputCaptureInterrupt();
  digitalWrite(LED_PIN, true);
}

ISR(TIMER3_COMPA_vect) {
  // Timer 3 Output Compare A Interrupt
  // Expected every 0.01 sec (100 times per seconds)
  speedMeas.onTimerOverflowInterrupt();
}

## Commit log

2023-04-06 ros realsense is working on jetson with cuda support
2023-05-02 [Hardware][WIP] reading IMU and publishing odom
    - basic node that publishes IMU message type from nav_msgs package.
    - links to realsense SKD and read IMU from realsesne.
    - Swapped the D435i with D435
    - Unit test works, receiving imu from T265 and depth from D435
2023-05-14 - Added a new message "Control" that has throttle and steering values - Added a new node to convert the Joy messages to Control messages - Change the Joy and PCA nodes to accomodate these changes.
2023-07-15 Files related to the Gear tooth Sensor as Encoder for DonkeyJet
    [encoder-B_Cu.gbr, encoder-B_Mask.gbr, encoder-B_Paste.gbr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]
